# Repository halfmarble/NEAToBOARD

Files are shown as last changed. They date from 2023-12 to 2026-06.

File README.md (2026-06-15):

# NEAToBOARD

An open-source **ESP32-WROOM-32 development board** by [halfmarble](https://halfmarble.com), designed in KiCad. NEAToBOARD breaks the ESP32 out onto a breadboard-friendly board with USB, on-board programming, a battery power path, and a built-in set of I/O for learning and prototyping.

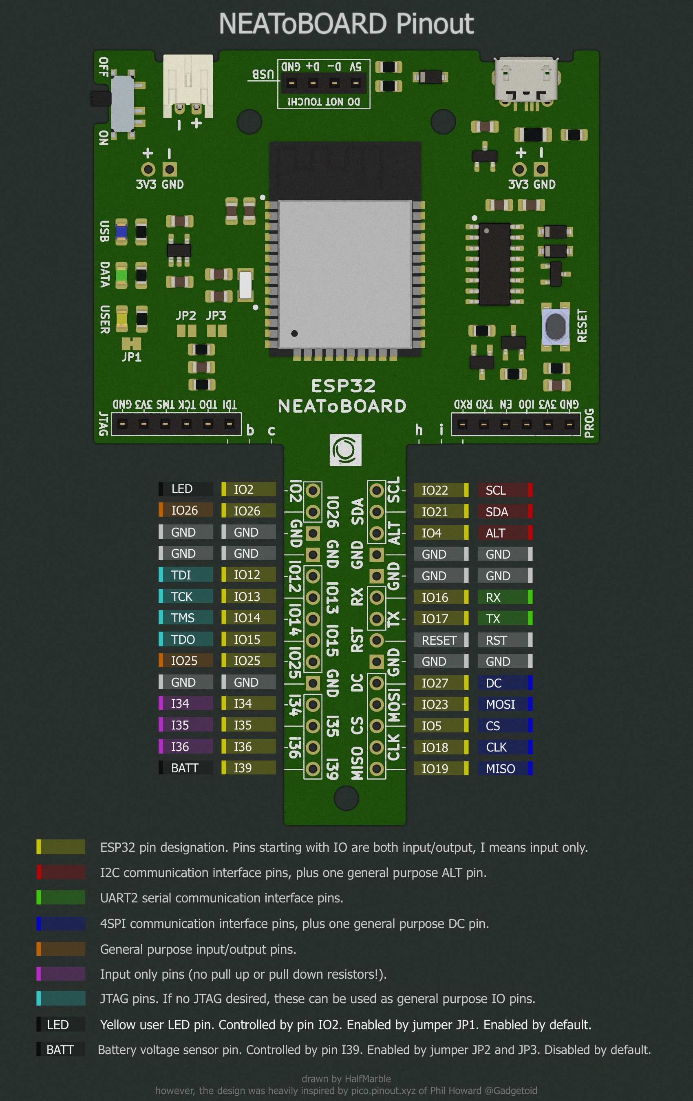
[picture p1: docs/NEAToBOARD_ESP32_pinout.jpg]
Pinout


## Features

- **ESP32-WROOM-32** module
- **USB micro-B** with a CH340C USB-to-UART bridge and the standard auto-reset / auto-bootloader circuit (no need to press buttons to flash)
- **Reset** and **two general-purpose** push buttons
- **Battery support** — JST-PH VBAT input with a Schottky power-path and a voltage divider for battery sensing, plus a 500 mA resettable fuse
- **32.768 kHz crystal** for the RTC / deep-sleep timekeeping
- On-board I/O for experimentation: a **5×4 LED matrix**, **RGB LED** (WS2812B), and discrete **feedback LEDs**
- **I²C** header plus a **Qwiic** connector, and an **SPI** header
- **JTAG** header for debugging
- M2 mounting holes; panelized with mouse-bite tabs

See the [full schematic (PDF)](docs/NEAToBOARD_ESP32.pdf) and the [pinout diagram](docs/NEAToBOARD_ESP32_pinout.jpg).

## Repository layout

```
hardware/
  KiCad-project/        KiCad 7 project — open NEAToBOARD_ESP32.kicad_pro
    NEAToBOARD_ESP32.kicad_sch        main schematic
    NEAToBOARD_ESP32Extras.kicad_sch  sub-sheet
    NEAToBOARD_ESP32.kicad_pcb        board layout
    HalfMarble.pretty/    project footprint library
    HalfMarble.3dshapes/  project 3D models (.step/.wrl) and symbols
    board2pdf.config.ini  board2pdf plugin config (fabrication PDFs)
    ibom.config.ini       InteractiveHtmlBom plugin config
    bom/                  rendered interactive BOM (bom.html)
    pinout/               pinout artwork source (pinout.pxd)
  3d/
    NEAToBOARD-ESP32.stl  3D-printable model of the board
docs/                   rendered schematic PDF and pinout image
BOM.csv                 bill of materials (values, footprints, manufacturer part numbers)
```

The authoritative source of truth is the KiCad schematic — `BOM.csv` is a convenience export so you can read the parts list without opening KiCad.

## Building / opening the design

Open `hardware/KiCad-project/NEAToBOARD_ESP32.kicad_pro` in **KiCad 7** (the files are saved in the `20221018` format). The custom footprint and 3D-model libraries are bundled inside the project and referenced with `${KIPRJMOD}`, so they load automatically — no global library setup required.

## Firmware

There is no firmware in this repository — NEAToBOARD runs **any ESP32 firmware**. Flash it with your toolchain of choice (Arduino core for ESP32, ESP-IDF, MicroPython, etc.) over the USB port; the on-board auto-reset/auto-bootloader circuit handles entering download mode, so no button presses are needed.

The pin layout is based on the **DFRobot FireBeetle ESP32** (with parts of **Adafruit's ESP32 board**). The simplest path is to target the **FireBeetle ESP32** board definition / pin map — most pins line up. If you select a different board definition, expect to **re-map a few GPIO assignments** to match this board; cross-check against the [pinout diagram](docs/NEAToBOARD_ESP32_pinout.jpg) and the [schematic](docs/NEAToBOARD_ESP32.pdf).

## Defensive publication / prior art

[`docs/defensive-publication/`](docs/defensive-publication/) contains a defensive
publication — *Synchronized Multi-Line Digital Signal Generation Using Plural Independent
Software-Triggered Serializer Peripherals With Open-Loop Fixed Start-Skew Compensation* —
published in the **Technical Disclosure Commons**, Defensive Publications Series
([www.tdcommons.org/dpubs_series/10442](https://www.tdcommons.org/dpubs_series/10442)), an
examiner-searched prior-art database, together with
load-bearing source excerpts. It documents, as dated public prior art, a technique for
synthesizing a USB full-speed D−/D+ differential signal on an ESP32 (a board like this
one) by driving two independent SPI controllers in lock-step: a CPU-fenced back-to-back
start makes the inter-unit skew deterministic, and a fixed configured MOSI delay cancels
it open-loop. It is published defensively to keep the technique freely practicable by all.

## License

The hardware design — schematic, PCB layout, footprint and 3D-model libraries, and the rest of the design files in this repository — is licensed under the **CERN Open Hardware Licence Version 2 – Permissive (CERN-OHL-P-2.0)**. See [`LICENSE`](LICENSE) for the full text. The defensive-publication document under [`docs/defensive-publication/`](docs/defensive-publication/) is licensed CC-BY-4.0, and the source excerpts therein retain their original Apache-2.0 headers.

> Copyright halfmarble 2023.
>
> This source describes Open Hardware and is licensed under the CERN-OHL-P v2. You may redistribute and modify this documentation and make products using it under the terms of the CERN-OHL-P v2 (https://ohwr.org/cern_ohl_p_v2.txt). This documentation is distributed WITHOUT ANY EXPRESS OR IMPLIED WARRANTY, INCLUDING OF MERCHANTABILITY, SATISFACTORY QUALITY AND FITNESS FOR A PARTICULAR PURPOSE. Please see the CERN-OHL-P v2 for applicable conditions.

## Acknowledgements

The pin layout and parts of the design are based on the [DFRobot FireBeetle ESP32](https://www.dfrobot.com/) and Adafruit's ESP32 board — both open-hardware designs. Thanks to those communities.

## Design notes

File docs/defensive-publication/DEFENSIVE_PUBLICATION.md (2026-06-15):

# Synchronized Multi-Line Digital Signal Generation Using Plural Independent Software-Triggered Serializer Peripherals With Open-Loop Fixed Start-Skew Compensation

**A Defensive Publication / Technical Disclosure to Establish Prior Art**

**Author:** Gerard Ziemski (Halfmarble LLC)
**Published:** Technical Disclosure Commons, Defensive Publications Series — [dpubs_series/10442](https://www.tdcommons.org/dpubs_series/10442)
**Date of first public disclosure:** 2026-06-05
**Version:** 1.0
**License:** Creative Commons Attribution 4.0 International (CC-BY-4.0).
*(The prior-art effect derives from the dated, enabling public disclosure itself, not from the license.)*
**Venue:** Technical Disclosure Commons, archived alongside the [halfmarble/NEAToBOARD](https://github.com/halfmarble/NEAToBOARD) open-hardware project.

---

> **Purpose of this document.** This is a *defensive publication*. It is released to
> place the techniques described herein, and reasonable generalizations of them, into
> the public domain as documented, dated, enabling prior art, so that they remain free
> for anyone to practice and cannot be removed from the public by a later patent. It is
> not an assertion of patent rights. The author makes no warranty and grants the
> permissions stated in the license above. A reference implementation predates this
> disclosure in the author's private records; this document is its first public
> disclosure.

---

## Abstract

A method is disclosed for generating two or more *time-aligned* digital output signals —
for example a differential pair such as the USB D−/D+ data lines, or more generally any
paired, differential, multi-phase, polyphase, quadrature, or multi-channel synchronized
output — on a microcontroller or system-on-chip (SoC) that provides **plural independent
hardware serializer peripherals** (such as two or more SPI master transmit/MOSI engines)
but provides **no single peripheral and no dedicated hardware** capable of driving the
desired multi-line signal directly. Each output line is assigned its own serializer and
preloaded with a precomputed bitstream. The serializers are started by **back-to-back
software trigger writes** (e.g., consecutive stores to each unit's start/command
register) that are preceded by CPU pipeline/memory-ordering **fence instructions**, which
quiesce the processor so that the unavoidable inter-unit start skew becomes **small,
fixed, and deterministic** rather than variable. That now-constant skew is then cancelled
**open-loop** by a single **fixed configured output delay** applied to the
later-emitting serializer (for example an SPI MOSI output delay expressed in fractions of
the bit clock, dummy lead bits, or a clock-phase offset), requiring no runtime
measurement or feedback. The result is that independent serializers, though triggered by
separate sequential software writes, emit in alignment to within a small fraction of a
bit period. A complete reduction to practice is described in which two SPI controllers of
an Espressif ESP32 synthesize a USB full-speed (12 Mbit/s) D−/D+ differential waveform,
enabling software USB host signaling on a chip lacking any USB peripheral.

## 1. Field and Motivation

Many digital interfaces carry information on two or more conductors that must transition
in a fixed, tight time relationship. The differential pair is the canonical case: a USB
receiver interprets the *difference* between D− and D+, so the two lines must be co-timed
to a small fraction of a bit period. Other examples include multi-phase clocking,
quadrature signaling, and multi-channel arbitrary waveform or LED-array generation where
channels must remain phase-aligned.

A microcontroller lacking dedicated hardware for such a signal (e.g., no USB
PHY/serial-interface engine, and no differential serializer) is conventionally forced to
"bit-bang" the signal by toggling general-purpose I/O (GPIO) from cycle-counted CPU code.
This consumes the CPU, is intolerant of interrupt jitter, and is limited by the per-bit
instruction budget — on common parts capping bit-banged USB at *low speed* (1.5 Mbit/s)
rather than *full speed* (12 Mbit/s).

A hardware serializer peripheral — for instance an SPI master operated transmit-only
(MOSI-only) — is effectively a hardware shift register that clocks a precomputed buffer
out of memory at a precise rate with no per-bit CPU involvement, and can therefore sustain
higher line rates. But a single such peripheral drives only **one** line, while the target
signal needs **two or more co-timed** lines. The natural idea — use one serializer per
line — runs into a synchronization problem: the serializers are independent units, each
started by its own trigger, and software can only trigger them in sequence, so one unit
begins shifting one or more instruction-times before the others. At high bit rates this
inter-unit *start skew* is a significant fraction of a bit period and corrupts the paired
signal. This disclosure solves that problem.

## 2. The Technique

The method comprises the following elements; elements (a)–(c) are the core combination,
and (d)–(g) are advantageous additions.

**(a) Per-line independent serializers.** Each of N ≥ 2 output lines is assigned to its
own independently-triggerable hardware serializer peripheral, each preloaded with the
precomputed bitstream for its line.

**(b) Deterministic-skew start via a CPU fence.** The serializers are triggered by writing
their respective start/trigger control values in **immediate succession** (e.g.,
consecutive stores to each unit's command register). Immediately *before* these writes, one
or more CPU pipeline/memory-ordering **fence/synchronization operations** are executed to
bring the processor to a quiescent state, so that the trigger writes issue with a
**minimal and deterministic** inter-unit skew (on the order of a single store
instruction) rather than a variable one influenced by prior in-flight memory or exception
activity.

**(c) Open-loop fixed compensating delay.** The later-emitting serializer(s) are
configured with a **fixed, constant output delay** sized to cancel the deterministic skew
from (b), so that all lines emit their first and subsequent bits in alignment. Because (b)
makes the skew constant, a single fixed delay value suffices; **no runtime feedback,
measurement, or closed-loop adjustment is required.**

**(d) Idle-level inversion with software pre-inversion.** Where the protocol idle level
differs from the serializer's idle level, one serializer's output path is inverted (e.g.,
via the I/O routing matrix or pin polarity) to rest at the protocol idle level, and that
line's data buffer is pre-inverted in software so the on-wire data remains correct.

**(e) Pre-encoded paired buffers.** The protocol physical layer (e.g., line coding such as
NRZI, run-length/bit-stuffing, framing, CRC) is computed ahead of time into per-line
buffers expressed as a sequence of per-bit line-state tuples, then split into the per-line
serializer buffers; buffers may reside in DMA-capable memory and may be allocated
contiguously for cache locality.

**(f) Clock targeting by search.** Serializer clock prescaler/divider settings are selected
by searching the divider space for the combination that most closely approximates a target
bit rate.

**(g) Execution-environment quiescing.** The trigger routine runs pinned to a processor
core at elevated priority and, during the timing-critical window, disables interrupts /
enters a critical section and resides in fast (non-cache-stalling) memory.

## 3. Reduction to Practice (Specific Embodiment: ESP32, USB Full Speed)

The following was reduced to practice on an Espressif ESP32 (dual-core Xtensa LX6), which
exposes two general-purpose SPI controllers ("HSPI" and "VSPI") and **no USB peripheral**.
Each controller is operated transmit-only (MOSI-only), 3-wire, half-duplex master. (Source
excerpts implementing the load-bearing steps accompany this document — see §7.)

- **Line/peripheral assignment.** USB **D− → GPIO12 via HSPI**; USB **D+ → GPIO13 via
  VSPI**. Together they form the USB differential pair.
- **Clock (element f).** A 12 MHz bit rate (USB full speed, ≈83.33 ns/bit) is obtained by
  iterating the controller prescaler and divider ranges and selecting the pair minimizing
  error versus 12 MHz; the resulting register value is programmed into both controllers.
  (`bitbangSPI.c`, `setup_clock`.)
- **Idle inversion (element d).** USB full speed idles with D+ high; an SPI line idles low.
  The D+ controller's serial output/input signal is routed through the I/O matrix with
  inversion enabled so the line idles high, and the D+ byte buffer is bitwise-complemented
  in software so the on-wire data is correct after the hardware inversion. Pin drive
  strength is set weak so an attached device can overpower the host lines as the protocol
  requires. (`bitbangSPI.c`, `bitbang_init`; `ubbPackets.c`, `_ubb_usb_add_description`.)
- **Encoding (element e).** For each packet (SOF, SETUP token, DATA/device-request,
  ACK/NAK), packet bytes are assembled with correct field order, bit-endianness, and
  CRC5/CRC16; the byte stream is NRZI-encoded with a forced transition stuffed after six
  consecutive 1s, and an EOP plus idle filler appended. Each symbol is expressed as a D−/D+
  level pair and written into the HSPI buffer (D−) and the pre-inverted VSPI buffer (D+),
  both in DMA-capable memory. (`ubbPackets.c`, `ubb_usb_add_data`; `crc.c`.)
- **Synchronized start (elements b, c).** With both controllers preloaded, the routine
  executes a fence — on Xtensa: `excw;` then `isync; dsync; esync;` then several `nop`s —
  immediately followed by back-to-back stores of the "user start" command value to each
  controller's command register (`spi1->cmd.val = ONE; spi2->cmd.val = ONE;`). The
  fence makes controller 1 lead controller 2 by a fixed, minimal interval. At
  initialization, a fixed MOSI output delay (expressed in eighths of the bit-clock period)
  is configured on the appropriate controller so that this constant skew is cancelled and
  D−/D+ transition together. An optional busy-spin waits for both units' start bits to
  self-clear. (`bitbangSPI.c`, `bitbang_write_impl` and the `delay` branch of
  `bitbang_init`.)
- **Timing isolation (element g).** The transmit routine runs as a highest-priority task
  pinned to the application core; during transmission it disables interrupts / enters a
  critical section (logging suppressed) and runs from instruction RAM. Inter-packet timing
  (e.g., 1 ms keep-alive SOF cadence) is produced by busy-wait.
- **Result.** The two independent controllers jointly emit a valid USB full-speed
  differential waveform sufficient to drive bus reset, keep-alive, and control transfers
  (e.g., a SET_ADDRESS enumeration step) on a microcontroller having no USB hardware.

## 4. Generalizations Disclosed (Defensive Scope)

The following generalizations are expressly disclosed as part of this prior art so that
neither the specific technique nor these variations may later be removed from the public
domain by patent:

- **Number of lines.** N ≥ 2 lines, each driven by its own serializer, triggered in
  succession, with a per-unit fixed compensating delay sized to each unit's deterministic
  skew.
- **Type of serializer.** Any hardware peripheral that shifts a buffer out at a clocked
  rate and is independently triggerable — SPI master MOSI, I2S/PCM transmitter, UART/USRT,
  dedicated shift-register block, timer output-compare/PWM-pattern engine, or programmable
  I/O serializer.
- **Means of making the skew deterministic.** Any pipeline/memory-barrier or
  instruction-ordering construct appropriate to the architecture (e.g., Xtensa
  `excw`/`isync`/`dsync`/`esync`, ARM `DSB`/`ISB`, RISC-V `fence`), and/or issuing the
  triggers from a single uninterruptible window, and/or any single-transaction multi-unit
  trigger the hardware permits.
- **Means of the compensating delay.** A configured serializer output delay, inserted
  fixed dummy/lead bits in the earlier-emitting buffer, a clock-phase offset, an earlier
  clock-enable of the lagging unit, or preamble padding — all **open-loop** (fixed,
  without runtime feedback).
- **Idle-level establishment.** Inverting one serializer's routed output with software
  pre-inversion, external inverting buffers, configurable pin polarity, or
  serializer idle/clock-polarity settings.
- **Target signal / protocol.** USB at low, full, or higher speeds as the processor
  allows; any other protocol or signal carried on two or more co-timed lines —
  differential, single-ended paired, multi-phase, polyphase, quadrature, or multi-channel
  phase-aligned (including multi-channel DAC or LED-array drive).
- **Processor/SoC.** Any single- or multi-core microcontroller or SoC with plural
  independent serializers. In a multi-core variant the per-line triggers may issue from
  different cores configured to fire within a bounded window, again with a fixed
  compensating delay.
- **Encoding.** Any line coding precomputed into the paired buffers as appropriate to the
  target protocol.

## 5. Relationship to Prior Art

This section surveys the surrounding public art and states precisely what is, and is not,
believed novel, so that the defensive disclosure is accurate and its distinguishing
combination is clear. Three categories of prior art are adjacent but distinct.

**5.1 Single peripheral driving multiple lines (no inter-unit skew exists).**
A large body of work drives several output lines from **one** serializer or one
parallel-output peripheral, so the synchronization problem addressed here does not arise:
ESP32/ESP8266 LED drivers serialize many parallel LED lanes from a **single I2S**
peripheral with DMA — e.g., the FastLED ESP32 parallel driver [7], the
*I2SClocklessLedDriver* (16 lanes from one I2S) [6], and cnlohr's *esp8266ws2812i2s*
(WS2812 from one I2S) [11]; quad-SPI (QSPI) drives four synchronized data lines from a
**single** master, e.g., US 9,734,099 B1 [10]. Inter-line alignment in all these is
inherent to using one peripheral and is **not** the problem solved here.

**5.2 Repurposing one serializer as a bit-stream generator for an unsupported protocol.**
Vendor application notes emulate one protocol with a single peripheral of another type —
e.g., I²S emulated on a **single SPI** with a timer generating the word-select frame: ST
AN5086 [4] and NXP AN4944 [12]. These establish the general idea of abusing a serializer
as a bitstream generator, but use a **single** unit and therefore present **no inter-unit
start-skew** to solve.

**5.3 Multi-serializer alignment by hardware clock sync or closed-loop skew control.**
Where multiple serializers *are* aligned, the art does so by **hardware** means, not by a
software-fenced start plus open-loop fixed delay on a commodity MCU:

- **FPGA SERDES:** multiple OSERDES blocks are aligned by a **shared, phase-aligned clock
  and a common synchronous reset**, optionally with a forwarded-clock training pattern —
  Xilinx XAPP585 [8] and XAPP704 (16 OSERDES from one clocking module) [9].
- **Cross-chip clock injection:** synchronizing serializers across separate RP2040 chips
  is done by driving a common oscillator into each chip's clock input and using PIO
  synchronized interrupts — Weber et al. (2025) [13].
- **Integrated / closed-loop skew compensation:** per-channel programmable skew delays
  exist **inside integrated multi-channel transmitters/SERDES**, set from on-chip
  registers/SRAM (US 8,081,706 B2 [1]), as fine analog differential pre-skew (US
  2015/0028929 A1 [2]), or **tuned by receiver feedback** to meet an interface spec such
  as SFI-5 (US 7,467,056 [3]); related receive-side deskew appears in TI TIDUA38 [14].
  These are integrated and/or closed-loop, not an open-loop fixed delay applied to a
  second discrete, software-started serializer.

**5.4 What is believed novel — the combination.** No located prior art combines all of:
(i) **two or more fully independent serializer peripherals** on one MCU/SoC, each driving
one line of a co-timed multi-line output; (ii) started by **back-to-back software trigger
writes made deterministic by a CPU pipeline/memory fence**; (iii) with inter-unit start
skew cancelled **open-loop by a single fixed configured output delay** (no feedback); and
(iv) applied to produce a **differential (or otherwise paired/multi-phase) signal on a
part that has no native peripheral for that signal** — reduced to practice as a USB
full-speed D−/D+ generator on the ESP32. The contribution is this *combination*; each
ingredient individually is known, but their assembly to solve co-timed multi-line output
on a commodity MCU without dedicated hardware is not shown in the located art. (This is an
absence-of-evidence conclusion over a non-exhaustive public corpus, not a proof of
non-existence.)

## 6. Statement for the Public Record

The author publishes the technique of §2, the embodiment of §3, and the generalizations of
§4 as prior art, effective on the date of first public disclosure stated above, to ensure
they remain freely practicable by all and to bar their later removal from the public
domain by patent.

## 7. Reference Implementation (Excerpts)

The load-bearing portions of a working reference implementation (from the author's
"ubbUSB" Espressif ESP-IDF / PlatformIO project) accompany this disclosure in
[`reference-excerpts/`](reference-excerpts/), under the Apache License 2.0:

- **`bitbangSPI.c` / `bitbangSPI.h`** — dual independent SPI-controller initialization
  (`bitbang_init`), the fixed compensating MOSI delay (the `delay` branch), the
  brute-force clock search (`setup_clock`), and the fenced back-to-back synchronized start
  (`bitbang_write_impl`).
- **`ubbPackets.c` / `ubbPackets.h`** — the encoder: NRZI, bit-stuffing, EOP/framing, and
  the splitting of per-bit D−/D+ line-state pairs into the two per-line serializer buffers
  (`ubb_usb_add_data`, `_ubb_usb_add_description`), plus packet construction.
- **`crc.c` / `crc.h`** — USB CRC5 (token) and CRC16 (data) per the USB specification.

These are excerpts intended to make the disclosure enabling on the core claims; they are
not a standalone-buildable project (the full ubbUSB project additionally contains the
transmit task, top-level state machine, and build files). The excerpt files retain their
original Apache-2.0 headers; this disclosure document is CC-BY-4.0; the surrounding
NEAToBOARD hardware project is licensed separately (CERN-OHL-2). 

## References

[1] US 8,081,706 B2, *Reducing lane-to-lane skew* (per-channel SRAM-set delay in a
multi-channel transmitter). https://patents.google.com/patent/US8081706

[2] US 2015/0028929 A1, *Differential pre-skew* (fine analog delay ~0–28 ps).
https://patents.google.com/patent/US20150028929A1/en

[3] US 7,467,056, *Per-lane preskew tuned by receiver feedback (SFI-5)*.
https://image-ppubs.uspto.gov/dirsearch-public/print/downloadPdf/7467056

[4] STMicroelectronics, AN5086, *I2S protocol emulation on STM32L0 using a standard SPI
peripheral*.
https://www.st.com/resource/en/application_note/an5086-i2s-protocol-emulation-on-stm32l0-series-microcontrollers-using-a-standard-spi-peripheral-stmicroelectronics.p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

[5] ESP-IDF SPI Master driver documentation (ESP32 GP-SPI controllers SPI2/SPI3;
per-controller start). https://docs.espressif.com/projects/esp-idf/en/stable/esp32/api-reference/peripherals/spi_master.html

[6] hpwit, *I2SClocklessLedDriver* — 16 parallel LED lanes from one ESP32 I2S.
https://github.com/hpwit/I2SClocklessLedDriver

[7] FastLED, ESP32 parallel-output driver (single I2S, multiple lanes).
https://github.com/FastLED/FastLED/blob/master/src/platforms/esp/32/README.md

[8] Xilinx, XAPP585, *OSERDES output alignment via synchronous reset and forwarded clock*.
https://docs.amd.com/api/khub/documents/JlDZcsu8DsMLJ6KXAZfq5Q/content

[9] Xilinx, XAPP704, *16 OSERDES driven from one TX_CLOCKS clocking module*.
http://www.altera.co.kr/_xilinx/html/ref/V4AdvantageCD2/content/source/xapp704.pdf

[10] US 9,734,099 B1/B2, *Synchronized multi-line (QSPI) output from a single master*.
https://patents.google.com/patent/US9734099B1/en

[11] cnlohr, *esp8266ws2812i2s* — WS2812 LEDs via one ESP8266 I2S + DMA.
https://github.com/cnlohr/esp8266ws2812i2s

[12] NXP, AN4944, *Emulating I2S bus on Kinetis-M using SPI plus a timer for word-select*.
https://www.nxp.com/docs/en/application-note/AN4944.pdf

[13] Weber et al., *Synchronizing RP2040 serializers via common oscillator into XIN and
PIO synchronized interrupts*, IET (2025).
https://ietresearch.onlinelibrary.wiley.com/doi/full/10.1049/tje2.70067

[14] Texas Instruments, TIDUA38, *Receive-side (MISO) signal-path delay compensation*.
https://www.ti.com/lit/pdf/tidua38

[15] US 2007/0047667 A1; US 8,132,040 — additional inter-channel skew-compensation art.
https://patents.google.com/patent/US20070047667A1/en ·
https://www.freepatentsonline.com/8132040.html

---

*Prepared as a defensive publication. Not legal advice. Depositing this document publicly
(Technical Disclosure Commons [dpubs_series/10442](https://www.tdcommons.org/dpubs_series/10442); GitHub) is
a public disclosure establishing prior art as of the date above.*

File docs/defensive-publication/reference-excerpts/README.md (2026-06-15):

# Reference-implementation excerpts

These files are **excerpts** from the author's private *ubbUSB* project (an Espressif
ESP-IDF / PlatformIO firmware experiment), included to make the accompanying defensive
publication — [`../DEFENSIVE_PUBLICATION.md`](../DEFENSIVE_PUBLICATION.md),
Technical Disclosure Commons [dpubs_series/10442](https://www.tdcommons.org/dpubs_series/10442) — *enabling* on its
core claims.

They are provided **as-is, under the Apache License 2.0** (see the header in each file),
and are **not a standalone-buildable project**: the full ubbUSB project additionally
contains the transmit task, the top-level USB state machine, utility headers, and the
PlatformIO/ESP-IDF build files, which are not reproduced here.

| File | Role in the disclosed technique |
|---|---|
| `bitbangSPI.c` / `bitbangSPI.h` | Dual independent SPI-controller init (`bitbang_init`); fixed compensating MOSI delay (`delay` branch); brute-force clock search (`setup_clock`); **fenced back-to-back synchronized start** (`bitbang_write_impl`). |
| `ubbPackets.c` / `ubbPackets.h` | NRZI + bit-stuffing + EOP/framing encoder; splitting per-bit D−/D+ line-state pairs into the two per-line serializer buffers (`ubb_usb_add_data`, `_ubb_usb_add_description`). |
| `crc.c` / `crc.h` | USB CRC5 (token) and CRC16 (data) per the USB specification. |

The synchronized-start core is in `bitbangSPI.c`, function `bitbang_write_impl`: a
`excw; isync; dsync; esync;` fence and NOP padding immediately precede the two back-to-back
writes of the SPI "user start" bit to each controller's command register, after which the
fixed MOSI delay configured in `bitbang_init` cancels the resulting one-instruction skew.

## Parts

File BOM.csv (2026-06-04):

Reference | Value | Footprint | Qty | Manufacturer | Manufacturer Part Number
C1, C6 | 10uF | HalfMarble:C_0805_2012Metric_Pad1.18x1.45mm_HandSolder | 2 | Samsung Electro-Mechanics | CL21A106KPFNNNE
C2-C5, C7, C8, C11, C12 | 1uF | HalfMarble:C_0805_2012Metric_Pad1.18x1.45mm_HandSolder | 8 | Samsung Electro-Mechanics | CL21B105KOFNNNE
C9, C10 | 12pF | HalfMarble:C_0805_2012Metric_Pad1.18x1.45mm_HandSolder | 2 | YAGEO | CC0805JRNPO9BN120
D1, D3, D28 | BAT20J | HalfMarble:D_SOD-123 | 3 | Changjiang Electronics Tech (CJ) | B5819W
D2, D8-D27 | GREEN | HalfMarble:LED_0805_2012Metric_Pad1.15x1.40mm_HandSolder | 21 | XINGLIGHT | XL-2012UGC
D4 | BLUE | HalfMarble:LED_0805_2012Metric_Pad1.15x1.40mm_HandSolder | 1 | XINGLIGHT | XL-2012UBC
D5, D7 | YELLOW | HalfMarble:LED_0805_2012Metric_Pad1.15x1.40mm_HandSolder | 2 | Everlight Elec | 17-21SYGC/S530-E2/TR8
D6 | WS2812B | HalfMarble:LED_WS2812B_PLCC4_5.0x5.0mm_P3.2mm | 1 | Worldsemi | WS2812B-B/W
D29 | RED | HalfMarble:LED_0805_2012Metric_Pad1.15x1.40mm_HandSolder | 1 | Everlight Elec | 17-21SURC/S530-A3/TR8
F1 | 500mA | HalfMarble:Fuse_1206_3216Metric | 1 | Jinrui Electronic Materials Co. | JK-NSMD050-13.2V
H1-H3 | MountingHole | HalfMarble:MountingHole_2.2mm_M2_ISO7380 | 3
J1 | USB_B_Micro | HalfMarble:USB_Micro-B_Molex-105017-0001 | 1 | SHOU HAN | MicroXNJ
J2, J3 | 3.3V | HalfMarble:PinHeader_1x02_P2.54mm_Vertical | 2 | Nextron(Nextronics Engineering)
J4 | VBAT IN | HalfMarble:JST_PH_S2B-PH-K_1x02_P2.00mm_Horizontal | 1 | Ckmtw(Shenzhen Cankemeng)
J5 | JTAG | HalfMarble:PinSocket_1x06_P2.54mm_Vertical | 1 | BOOMELE(Boom Precision Elec)
J6, J7 | Header_01x14 | HalfMarble:PinHeader_1x14_P2.54mm_Vertical | 2 | Nextron(Nextronics Engineering) | Z-211-4011-0021-001
J8 | PROGRAM | HalfMarble:PinSocket_1x06_P2.54mm_Vertical | 1 | BOOMELE(Boom Precision Elec)
J9, J10, J15 | Header_01x01 | HalfMarble:PinHeader_1x01_P2.54mm_Small | 3
J11, J28 | Header_01x05 | HalfMarble:PinHeader_1x05_P2.54mm_Vertical | 2 | Nextron(Nextronics Engineering)
J12-J14, J16-J18, J26, J27, J29, J30 | Header_01x02 | HalfMarble:PinHeader_1x02_P2.54mm_Vertical | 10 | Nextron(Nextronics Engineering)
J19, J20, J24 | Socket_01x05 | HalfMarble:PinSocket_1x05_P2.54mm_Vertical | 3 | BOOMELE(Boom Precision Elec)
J21 | Socket_01x04 | HalfMarble:PinSocket_1x04_P2.54mm_Vertical | 1 | BOOMELE(Boom Precision Elec)
J22, J23 | Qwiic | HalfMarble:CONN_BM04B-SRSS-TB(LF)(SN) | 2 | JST Sales America | BM04B-SRSS-TB(LF)(SN)
J25 | Socket_01x02 | HalfMarble:PinSocket_1x02_P2.54mm_Vertical | 1 | BOOMELE(Boom Precision Elec)
J31 | Header_01x03 | HalfMarble:PinHeader_1x03_P2.54mm_Vertical | 1 | Nextron(Nextronics Engineering)
JP1, JP2 | Jumper (open) | HalfMarble:SolderJumper-2_P1.3mm_Open_Pad1.0x1.5mm | 2
JP3, JP4 | Jumper (bridged) | HalfMarble:SolderJumper-2_P1.3mm_Bridged_Pad1.0x1.5mm_Small | 2
LOGO1-LOGO3 | Logo_HalfMarble (silkscreen) | HalfMarble:LOGO | 3
LOGO4 | Logo_Open_Hardware (silkscreen) | Symbol:OSHW-Logo2_7.3x6mm_SilkScreen | 1
Q1, Q3 | S8050 | HalfMarble:TSOT-23 | 2 | Changjiang Electronics Tech (CJ) | S8050
Q2 | Si2301 | HalfMarble:SOT-23 | 1 | Vishay Intertech | SI2301CDS-T1-GE3
R1, R4, R5, R10, R17 | 10K | HalfMarble:R_0805_2012Metric_Pad1.20x1.40mm_HandSolder | 5 | Uniroyal Elec | 0805W8F1002T5E
R2 | 100K | HalfMarble:R_0805_2012Metric_Pad1.20x1.40mm_HandSolder | 1 | Uniroyal Elec | 0805W8J0104T5E
R3, R8, R11-R16, R20 | 2.7K | HalfMarble:R_0805_2012Metric_Pad1.20x1.40mm_HandSolder | 9 | Uniroyal Elec | 0805W8F2701T5E
R6, R9 | 470K 0.1% | HalfMarble:R_0805_2012Metric_Pad1.20x1.40mm_HandSolder | 2 | YAGEO | RT0805BRE07470RL
R7 | 3.9K | HalfMarble:R_0805_2012Metric_Pad1.20x1.40mm_HandSolder | 1 | Uniroyal Elec | 0805W8F3901T5E
R18, R19 | 22 | HalfMarble:R_0805_2012Metric_Pad1.20x1.40mm_HandSolder | 2 | Uniroyal Elec | 0805W8J0220T5E
R21, R22 | EMPTY (do not populate) | HalfMarble:R_0805_2012Metric_Pad1.20x1.40mm_HandSolder | 2
SW1, SW3-SW5 | Switch small | HalfMarble:PTS810SJG250SMTRLFS | 4 | Korean Hroparts Elec | K2-1808SN-A4SW-01
SW2 | Toggle | HalfMarble:SWITCH_SPST_SMD_A | 1 | Korean Hroparts Elec | K3-1296S-E1
U1 | USB LDO XC6206 | HalfMarble:SOT-23 | 1 | Torex Semicon | XC6206P332MR
U2 | USB-Serial CH340C | HalfMarble:SOIC-16_3.9x9.9mm_P1.27mm | 1 | WCH(Jiangsu Qin Heng) | CH340C
U3 | Main LDO ME6211 | HalfMarble:SOT-23-5 | 1 | MICRONE(Nanjing Micro One Elec) | ME6211C33M5G-N
U4 | ESP32-WROOM-32D | HalfMarble:ESP32-WROOM-32 | 1 | Espressif Systems | ESP32-WROOM-32D
U5, U8, U13, U16 | MouseBite (panel tab) | HalfMarble:MouseBiteHalf | 4
U6, U7, U9-U12, U14, U15 | MouseBite (panel tab) | HalfMarble:MouseBite | 8
Y1 | 32.768kHz crystal | HalfMarble:XTAL_ABS07-32.768KHZ-T | 1 | Seiko Epson | Q13FC1350000400

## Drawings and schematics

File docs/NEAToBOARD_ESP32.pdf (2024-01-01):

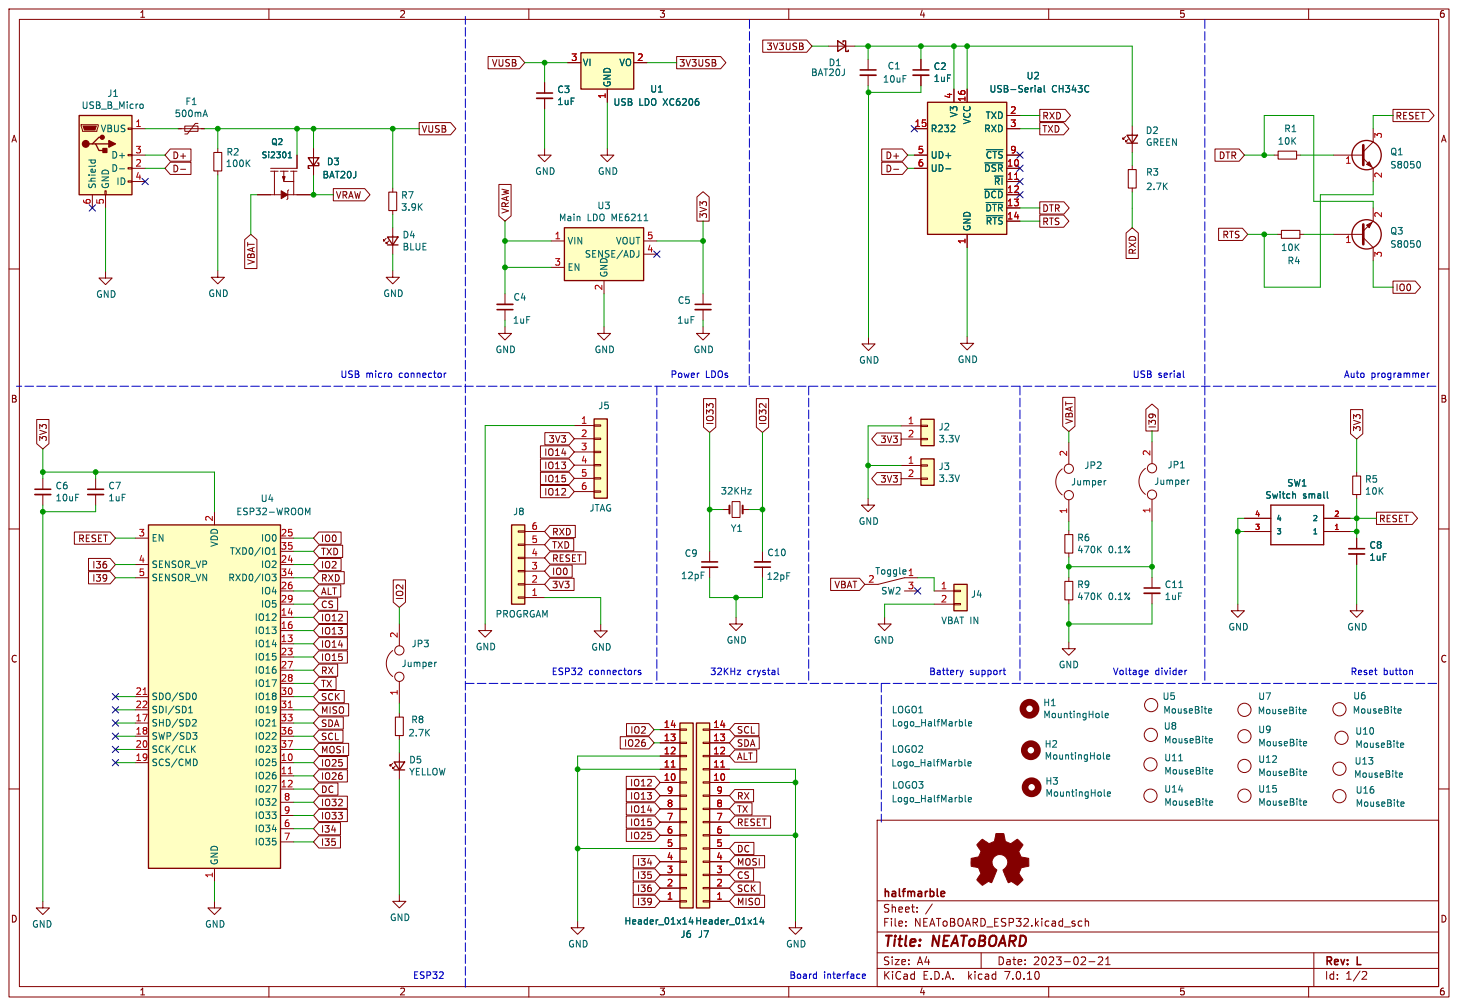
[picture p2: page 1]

1 VO 2 VI 3 U1 USB LDO XC6206 VIN 1 GND
GNDGND
1uF GND

4 UD+ 5 UD- 6 ~{CTS}9 U2 USB-Serial CH343C

1 ~{DSR} 10 ~{RI} 11 ~{DCD} 12 ~{DTR} 13 ~{RTS} 14 R232 15 VCC 16 TXD 2 RXD 3 V3

2 EN 3 SENSE/ADJ 4 VOUT 5 U3 Main LDO ME6211

2 SCK/CLK 20 SDO/SD0 21 SDI/SD1 22

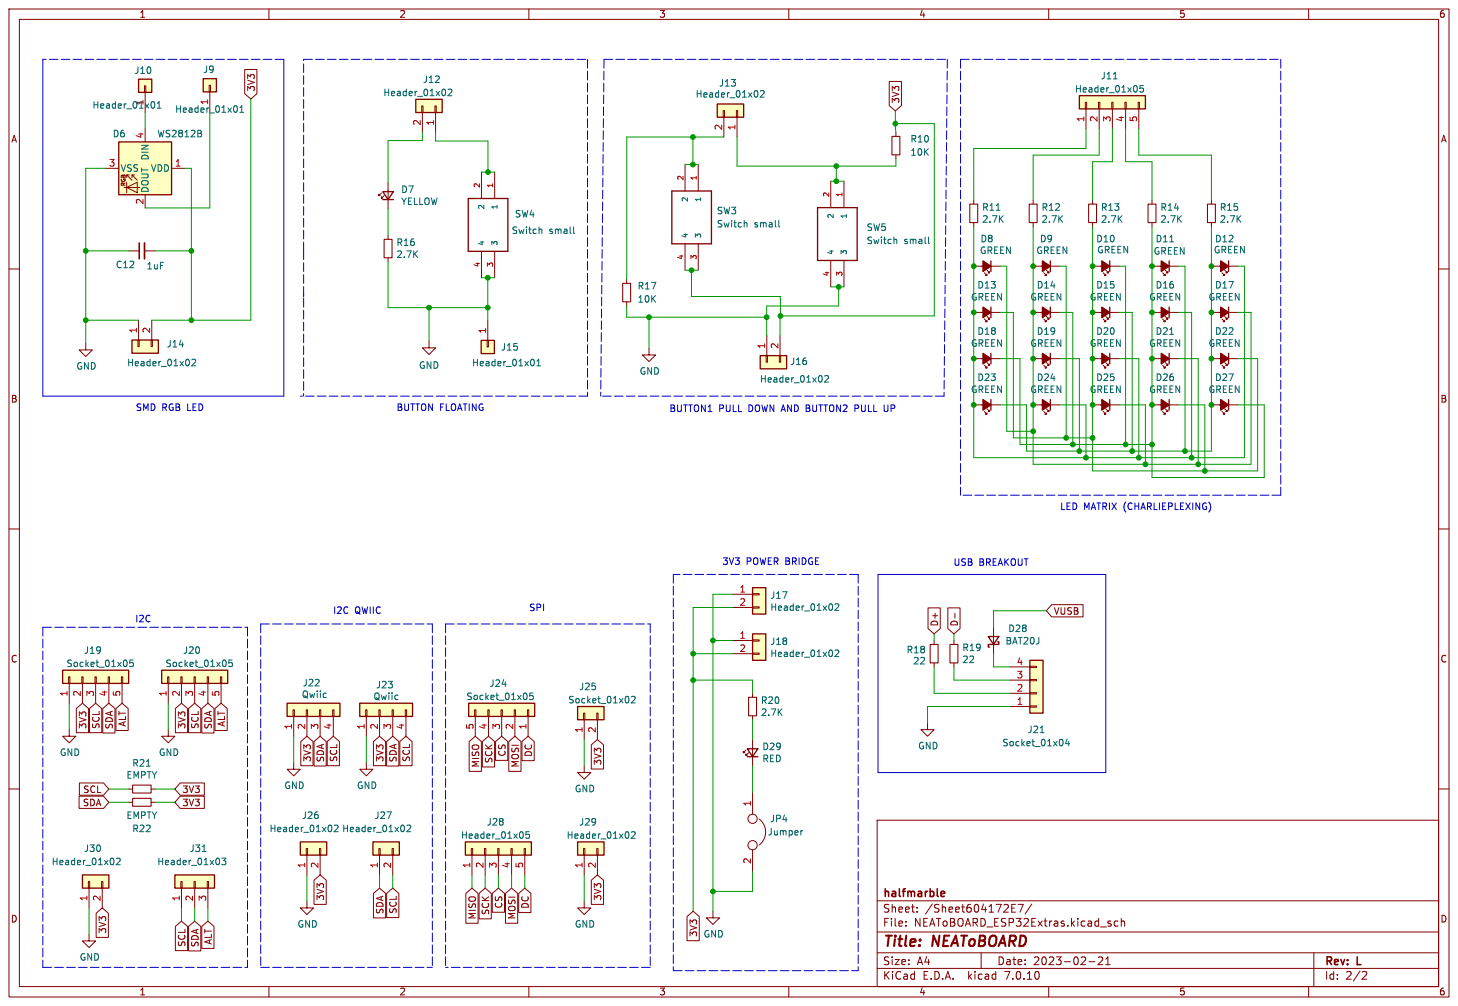
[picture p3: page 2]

USB BREAKOUT BUTTON1 PULL DOWN AND BUTTON2 PULL UP

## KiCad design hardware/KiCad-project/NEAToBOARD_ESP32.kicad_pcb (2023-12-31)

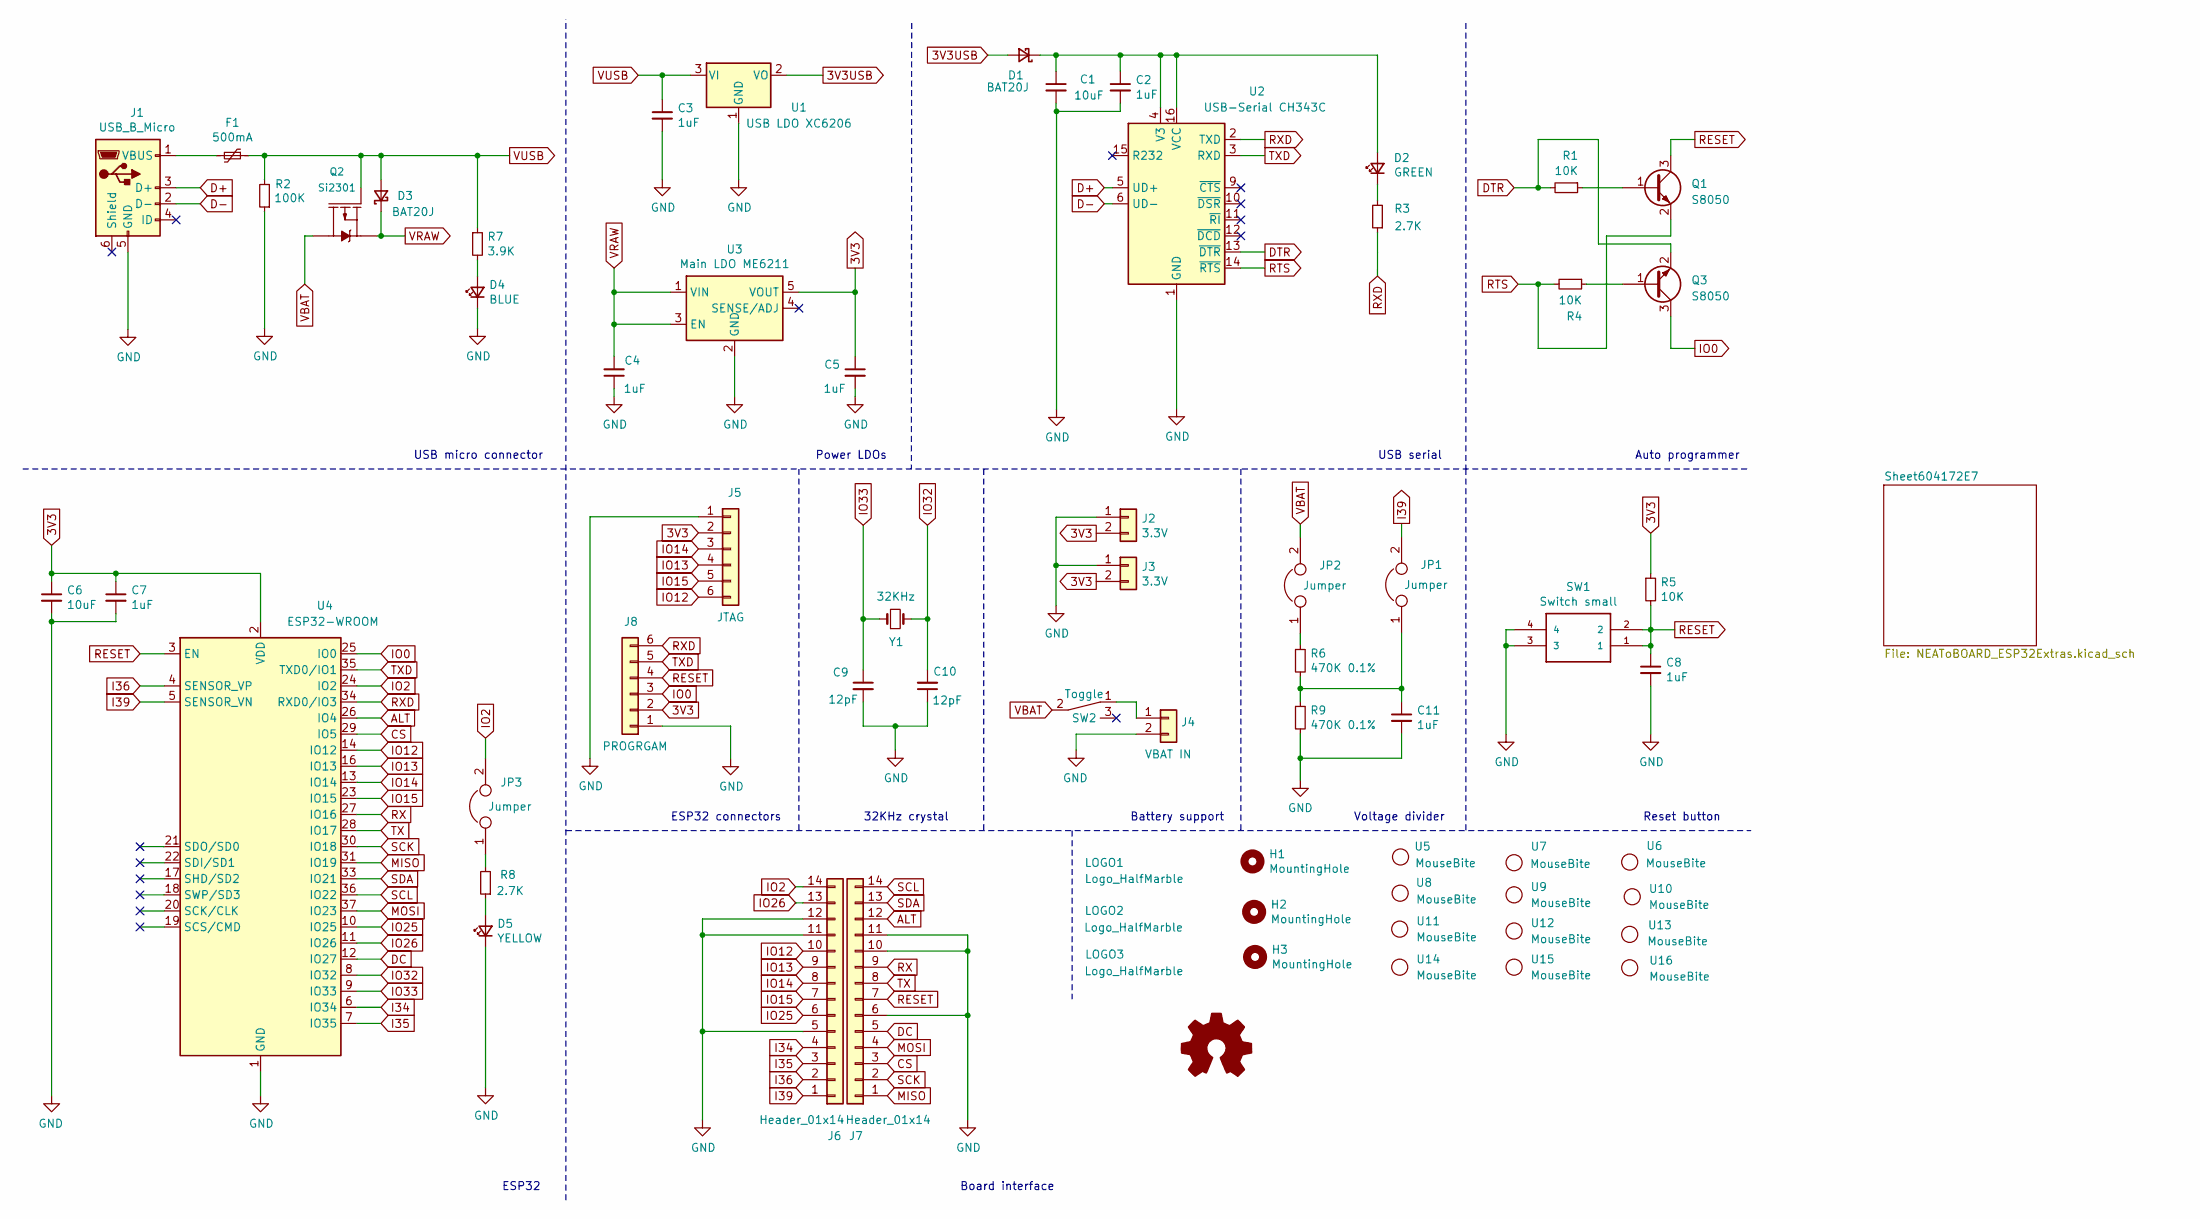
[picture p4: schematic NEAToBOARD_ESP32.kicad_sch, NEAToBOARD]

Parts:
C1, C6: 10uF; C_0805_2012Metric_Pad1.18x1.45mm_HandSolder; MANUFACTURER_PART_NUMBER CL21A106KPFNNNE; LCSC C17024
C2, C3, C4, C5, C7, C8, C11: 1uF; C_0805_2012Metric_Pad1.18x1.45mm_HandSolder; MANUFACTURER_PART_NUMBER CL21B105KOFNNNE; LCSC C24123
C9, C10: 12pF; C_0805_2012Metric_Pad1.18x1.45mm_HandSolder; MANUFACTURER_PART_NUMBER CC0805JRNPO9BN120; LCSC C107108
D1, D3: BAT20J; D_SOD-123; MANUFACTURER_PART_NUMBER B5819W; LCSC C8598
D2: GREEN; LED_0805_2012Metric_Pad1.15x1.40mm_HandSolder; MANUFACTURER_PART_NUMBER XL-2012UGC; LCSC C965815
D4: BLUE; LED_0805_2012Metric_Pad1.15x1.40mm_HandSolder; MANUFACTURER_PART_NUMBER XL-2012UBC; LCSC C965817
D5: YELLOW; LED_0805_2012Metric_Pad1.15x1.40mm_HandSolder; MANUFACTURER_PART_NUMBER 17-21SYGC/S530-E2/TR8; LCSC C73548
F1: 500mA; Fuse_1206_3216Metric; MANUFACTURER_PART_NUMBER JK-NSMD050-13.2V; LCSC C369159
H1, H2, H3: MountingHole; MountingHole_2.2mm_M2_ISO7380
J1: USB_B_Micro; USB_Micro-B_Molex-105017-0001; MANUFACTURER_PART_NUMBER MicroXNJ; LCSC C404969
J2, J3: 3.3V; PinHeader_1x02_P2.54mm_Vertical; LCSC C113597
J4: VBAT IN; JST_PH_S2B-PH-K_1x02_P2.00mm_Horizontal; MANUFACTURER_PART_NUMBER C155876; LCSC C155876
J5: JTAG; PinSocket_1x06_P2.54mm_Vertical; LCSC C40877
J6, J7: Header_01x14; PinHeader_1x14_P2.54mm_Vertical; MANUFACTURER_PART_NUMBER Z-211-4011-0021-001; LCSC C113597
J8: PROGRGAM; PinSocket_1x06_P2.54mm_Vertical; LCSC C40877
JP1, JP2: Jumper; SolderJumper-2_P1.3mm_Open_Pad1.0x1.5mm
JP3: Jumper; SolderJumper-2_P1.3mm_Bridged_Pad1.0x1.5mm_Small
LOGO1, LOGO2, LOGO3: Logo_HalfMarble; LOGO
LOGO4: Logo_Open_Hardware_Small; OSHW-Logo2_7.3x6mm_SilkScreen
Q1, Q3: S8050; TSOT-23; MANUFACTURER_PART_NUMBER S8050; LCSC C2146
Q2: Si2301; SOT-23; MANUFACTURER_PART_NUMBER SI2301CDS-T1-GE3; LCSC C10487
R1, R4, R5: 10K; R_0805_2012Metric_Pad1.20x1.40mm_HandSolder; MANUFACTURER_PART_NUMBER 0805W8F1002T5E; LCSC C17414
R2: 100K; R_0805_2012Metric_Pad1.20x1.40mm_HandSolder; MANUFACTURER_PART_NUMBER 0805W8J0104T5E; LCSC C25611
R3, R8: 2.7K; R_0805_2012Metric_Pad1.20x1.40mm_HandSolder; MANUFACTURER_PART_NUMBER 0805W8F2701T5E; LCSC C17530
R6, R9: 470K 0.1%; R_0805_2012Metric_Pad1.20x1.40mm_HandSolder; MANUFACTURER_PART_NUMBER RT0805BRE07470RL; LCSC C706281
R7: 3.9K; R_0805_2012Metric_Pad1.20x1.40mm_HandSolder; MANUFACTURER_PART_NUMBER 0805W8F3901T5E; LCSC C17614
SW1: Switch small; PTS810SJG250SMTRLFS; MANUFACTURER_PART_NUMBER K2-1808SN-A4SW-01; LCSC C92589
SW2: Toggle; SWITCH_SPST_SMD_A; MANUFACTURER_PART_NUMBER K3-1296S-E1; LCSC C128955
U1: USB LDO XC6206; SOT-23; MANUFACTURER_PART_NUMBER XC6206P332MR; LCSC C5446
U2: USB-Serial CH343C; SOIC-16_3.9x9.9mm_P1.27mm; MANUFACTURER_PART_NUMBER CH340C; LCSC C7464026
U3: Main LDO ME6211; SOT-23-5; MANUFACTURER_PART_NUMBER ME6211C33M5G-N; LCSC C82942
U4: ESP32-WROOM; ESP32-WROOM-32; MANUFACTURER_PART_NUMBER ESP32-WROOM-32E-N16; LCSC C701343
U5, U8, U13, U16: MouseBite; MouseBiteHalf
U6, U7, U9, U10, U11, U12, U14, U15: MouseBite
Y1: 32KHz; XTAL_ABS07-32.768KHZ-T; MANUFACTURER_PART_NUMBER Q13FC1350000400; LCSC C32346

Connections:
3V3USB: D1.2 (A), U1.2 (VO)
ALT: J7.12, U4.26 (IO4); also elsewhere on the board
CS: J7.3, U4.29 (IO5); also elsewhere on the board
D+: J1.3 (D+), U2.5 (UD+); also elsewhere on the board
D-: J1.2 (D-), U2.6 (UD-); also elsewhere on the board
DC: J7.5, U4.12 (IO27); also elsewhere on the board
DTR: Q3.2 (E), R1.2, U2.13 (~DTR)
I34: J6.4, U4.6 (IO34)
I35: J6.3, U4.7 (IO35)
I36: J6.2, U4.4 (SENSOR_VP)
I39: J6.1, JP1.2, U4.5 (SENSOR_VN)
IO0: J8.3, Q3.3 (C), U4.25 (IO0)
IO2: J6.14, JP3.2, U4.24 (IO2)
IO12: J5.6, J6.10, U4.14 (IO12)
IO13: J5.4, J6.9, U4.16 (IO13)
IO14: J5.3, J6.8, U4.13 (IO14)
IO15: J5.5, J6.7, U4.23 (IO15)
IO25: J6.6, U4.10 (IO25)
IO26: J6.13, U4.11 (IO26)
IO32: C10.2, U4.8 (IO32), Y1.2
IO33: C9.1, U4.9 (IO33), Y1.1
MISO: J7.1, U4.31 (IO19); also elsewhere on the board
MOSI: J7.4, U4.37 (IO23); also elsewhere on the board
unnamed: C11.1, JP1.1, R6.2, R9.1
unnamed: C1.1, C2.1, D1.1 (K), D2.2 (A), U2.4 (V3), U2.16 (VCC)
unnamed: D2.1 (K), R3.2
unnamed: D4.2 (A), R7.2
unnamed: D5.2 (A), R8.1
unnamed: F1.2, J1.1 (VBUS)
unnamed: J4.1, SW2.1
unnamed: JP2.1, R6.1
unnamed: JP3.1, R8.2
unnamed: Q1.1 (B), R1.1
unnamed: Q3.1 (B), R4.1
RESET: C8.1, J7.7, J8.4, Q1.3 (C), R5.2, SW1.1, SW1.2, U4.3 (EN)
RTS: Q1.2 (E), R4.2, U2.14 (~RTS)
RX: J7.9, U4.27 (IO16)
RXD: J8.6, R3.1, U2.2 (TXD), U4.34 (RXD0/IO3)
SCK: J7.2, U4.30 (IO18); also elsewhere on the board
TX: J7.8, U4.28 (IO17)
TXD: J8.5, U2.3 (RXD), U4.35 (TXD0/IO1)
VBAT: JP2.2, Q2.3 (D), SW2.2
VRAW: C4.2, D3.1 (K), Q2.2 (S), U3.1 (VIN), U3.3 (EN)
VUSB: C3.1, D3.2 (A), F1.1, Q2.1 (G), R2.2, R7.1, U1.3 (VI); also elsewhere on the board

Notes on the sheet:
Voltage divider
Board interface
Battery support
Reset button
32KHz crystal
ESP32
Auto programmer
Power LDOs
USB serial
ESP32 connectors
USB micro connector

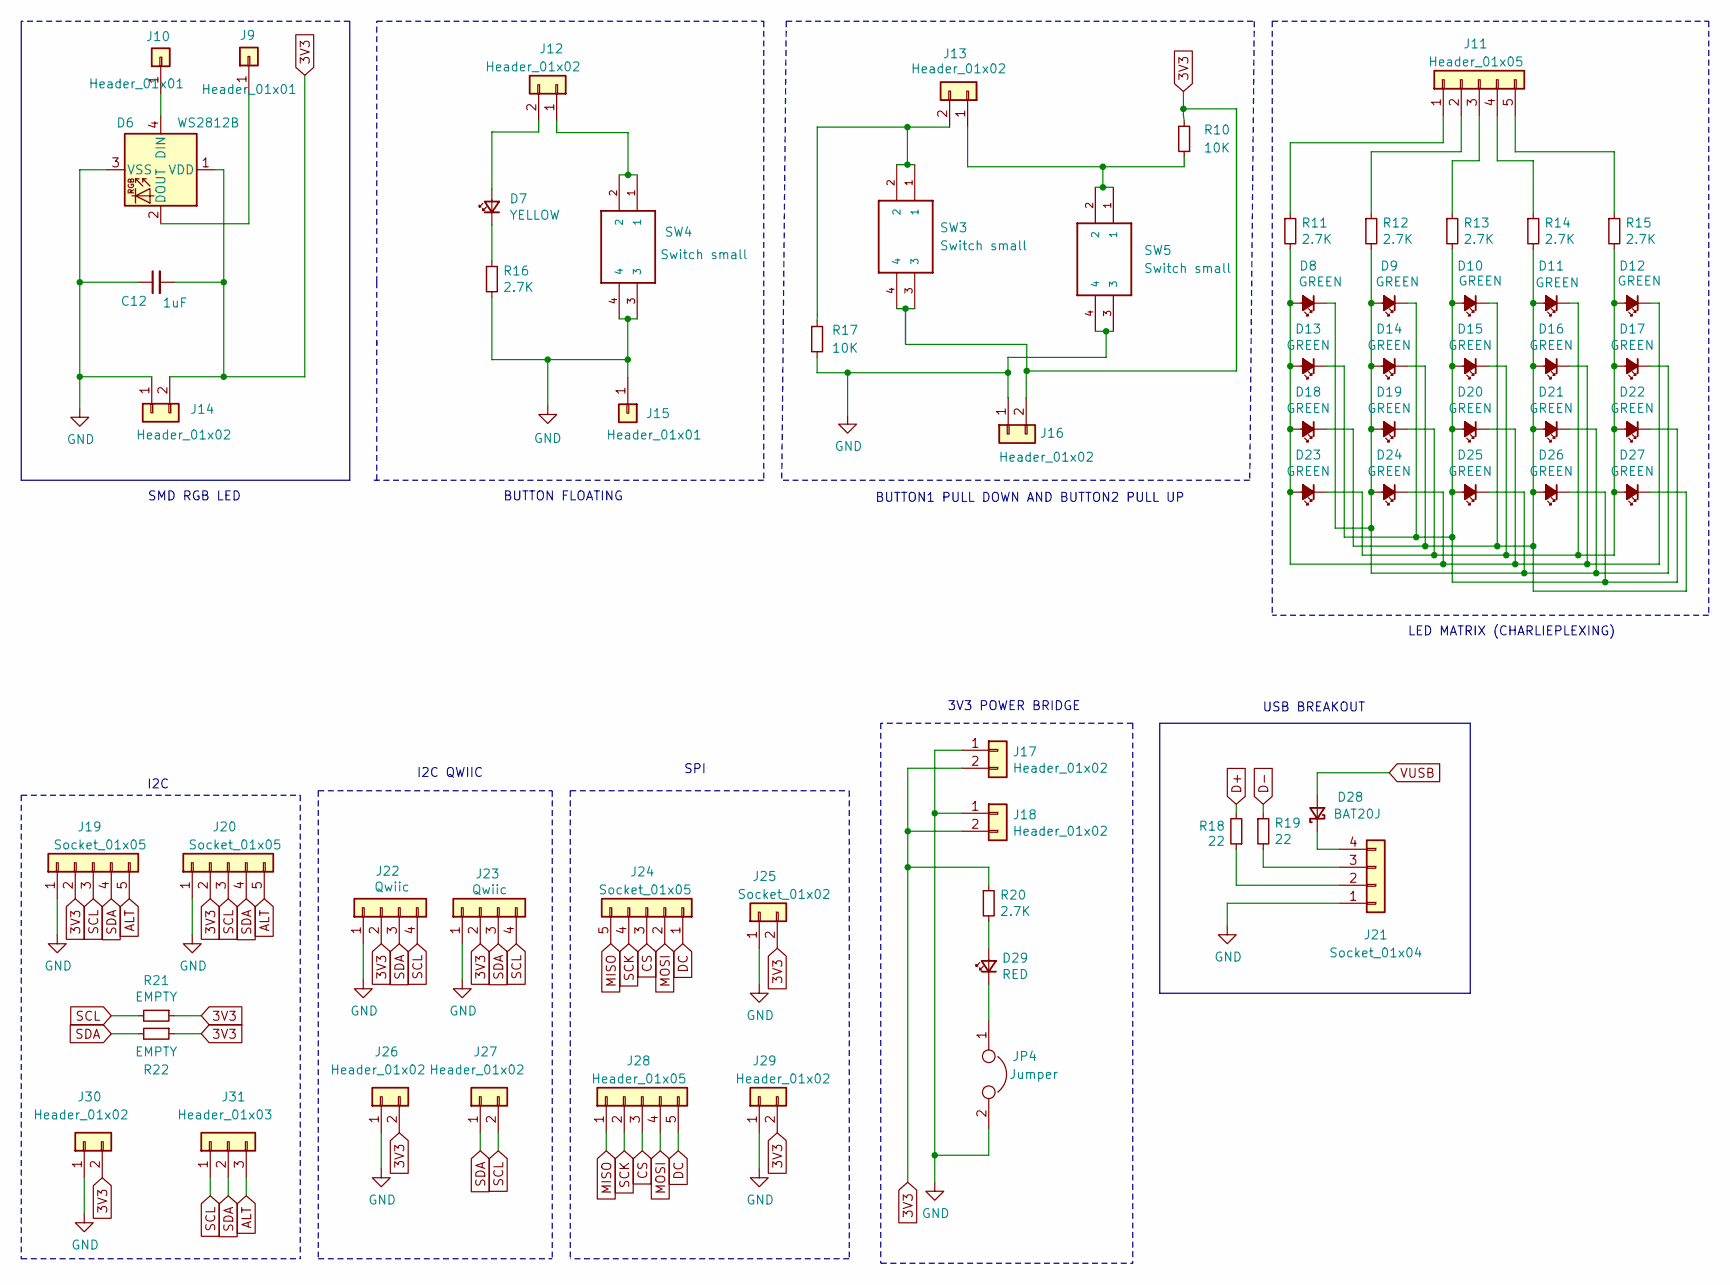
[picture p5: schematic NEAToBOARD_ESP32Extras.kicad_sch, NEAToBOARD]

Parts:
C12: 1uF; C_0805_2012Metric_Pad1.18x1.45mm_HandSolder; MANUFACTURER_PART_NUMBER CL21B105KOFNNNE; LCSC C24123
D6: WS2812B; LED_WS2812B_PLCC4_5.0x5.0mm_P3.2mm; MANUFACTURER_PART_NUMBER WS2812B-B/W; LCSC C2761795
D7: YELLOW; LED_0805_2012Metric_Pad1.15x1.40mm_HandSolder; MANUFACTURER_PART_NUMBER 17-21SYGC/S530-E2/TR8; LCSC C73548
D8, D9, D10, D11, D12, D13, D14, D15, D16, D17, D18, D19, D20, D21, D22, D23, D24, D25, D26, D27: GREEN; LED_0805_2012Metric_Pad1.15x1.40mm_HandSolder; MANUFACTURER_PART_NUMBER XL-2012UGC; LCSC C965815
D28: BAT20J; D_SOD-123; MANUFACTURER_PART_NUMBER B5819W; LCSC C8598
D29: RED; LED_0805_2012Metric_Pad1.15x1.40mm_HandSolder; MANUFACTURER_PART_NUMBER 17-21SURC/S530-A3/TR8; LCSC C72037
J9, J10, J15: Header_01x01; PinHeader_1x01_P2.54mm_Small; LCSC C113597
J11, J28: Header_01x05; PinHeader_1x05_P2.54mm_Vertical; LCSC C113597
J12, J13, J14, J16, J17, J18, J26, J27, J29, J30: Header_01x02; PinHeader_1x02_P2.54mm_Vertical; LCSC C113597
J19, J20, J24: Socket_01x05; PinSocket_1x05_P2.54mm_Vertical; LCSC C50950
J21: Socket_01x04; PinSocket_1x04_P2.54mm_Vertical; LCSC C2718488
J22, J23: Qwiic; CONN_BM04B-SRSS-TB(LF)(SN); MANUFACTURER_PART_NUMBER BM04B-SRSS-TB(LF)(SN); LCSC C160390
J25: Socket_01x02; PinSocket_1x02_P2.54mm_Vertical; LCSC C49661
J31: Header_01x03; PinHeader_1x03_P2.54mm_Vertical; LCSC C113597
JP4: Jumper; SolderJumper-2_P1.3mm_Bridged_Pad1.0x1.5mm_Small
R10, R17: 10K; R_0805_2012Metric_Pad1.20x1.40mm_HandSolder; MANUFACTURER_PART_NUMBER 0805W8F1002T5E; LCSC C17414
R11, R12, R13, R14, R15, R16, R20: 2.7K; R_0805_2012Metric_Pad1.20x1.40mm_HandSolder; MANUFACTURER_PART_NUMBER 0805W8F2701T5E; LCSC C17530
R18, R19: 22; R_0805_2012Metric_Pad1.20x1.40mm_HandSolder; MANUFACTURER_PART_NUMBER 0805W8J0220T5E; LCSC C17561
R21, R22: EMPTY; R_0805_2012Metric_Pad1.20x1.40mm_HandSolder
SW3, SW4, SW5: Switch small; PTS810SJG250SMTRLFS; MANUFACTURER_PART_NUMBER K2-1808SN-A4SW-01; LCSC C92589

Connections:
ALT: J19.5, J20.5, J31.3; also elsewhere on the board
CS: J24.3, J28.3; also elsewhere on the board
D+: R18.2; also elsewhere on the board
D-: R19.1; also elsewhere on the board
DC: J24.1, J28.5; also elsewhere on the board
MISO: J24.5, J28.1; also elsewhere on the board
MOSI: J24.2, J28.4; also elsewhere on the board
unnamed: D6.4 (DIN), J10.1
unnamed: D6.2 (DOUT), J9.1
unnamed: D7.2 (A), J12.2
unnamed: D9.1 (K), D10.2 (A), D13.1 (K), D15.2 (A), D20.2 (A), D22.1 (K), D25.2 (A), D26.1 (K), R13.2
unnamed: D10.1 (K), D11.2 (A), D14.1 (K), D16.2 (A), D18.1 (K), D21.2 (A), D26.2 (A), D27.1 (K), R14.2
unnamed: D8.2 (A), D12.1 (K), D13.2 (A), D16.1 (K), D18.2 (A), D20.1 (K), D23.2 (A), D24.1 (K), R11.2
unnamed: D8.1 (K), D9.2 (A), D14.2 (A), D17.1 (K), D19.2 (A), D21.1 (K), D24.2 (A), D25.1 (K), R12.2
unnamed: D28.1 (K), J21.4
unnamed: D29.2 (A), R20.2
unnamed: D29.1 (K), JP4.1
unnamed: J11.1, R11.1
unnamed: J11.2, R12.1
unnamed: J11.3, R13.1
unnamed: J11.4, R14.1
unnamed: J12.1, SW4.1, SW4.2
unnamed: J13.1, R10.1, SW5.1, SW5.2
unnamed: J13.2, R17.1, SW3.1, SW3.2
unnamed: J21.2, R18.1
unnamed: J21.3, R19.2
SCK: J24.4, J28.2; also elsewhere on the board
VUSB: D28.2 (A); also elsewhere on the board

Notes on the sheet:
I2C QWIIC
LED MATRIX (CHARLIEPLEXING)
USB BREAKOUT
I2C
BUTTON FLOATING
SMD RGB LED
3V3 POWER BRIDGE
SPI
BUTTON1 PULL DOWN AND BUTTON2 PULL UP

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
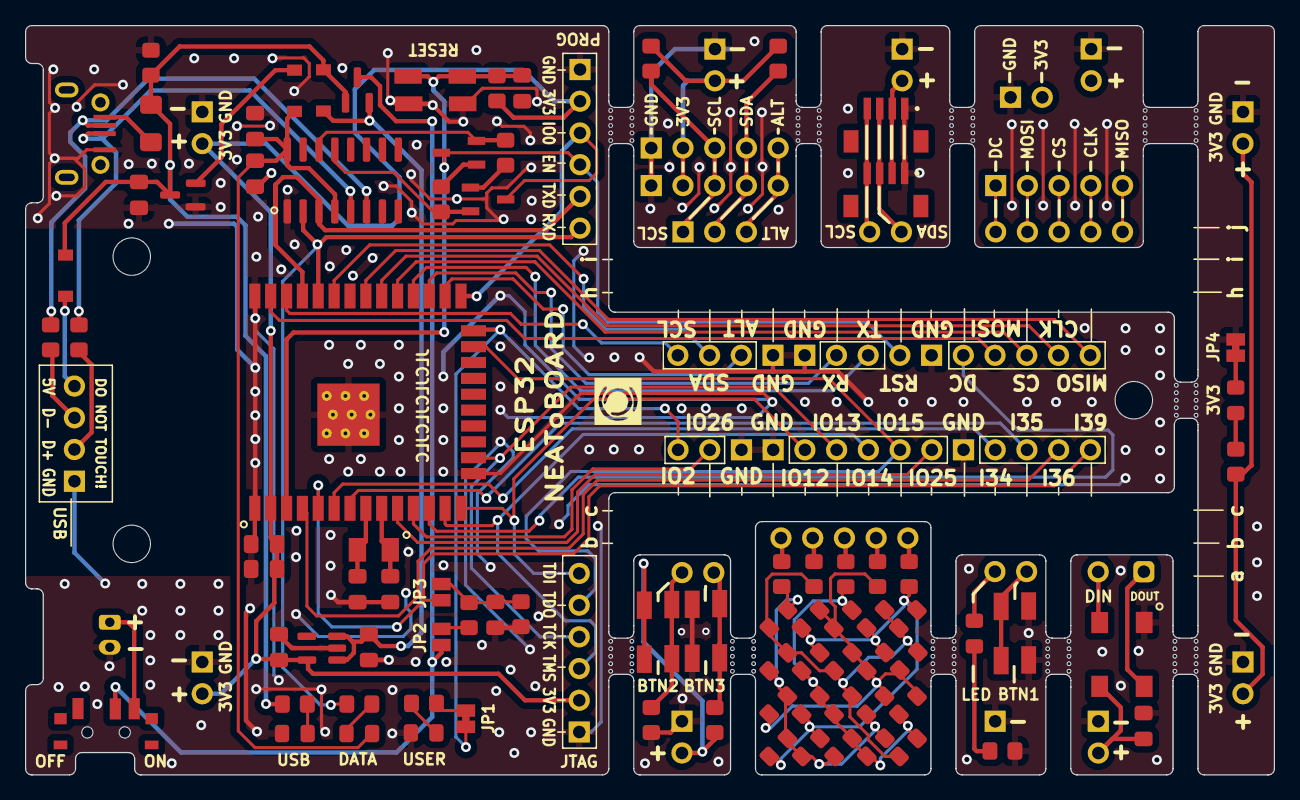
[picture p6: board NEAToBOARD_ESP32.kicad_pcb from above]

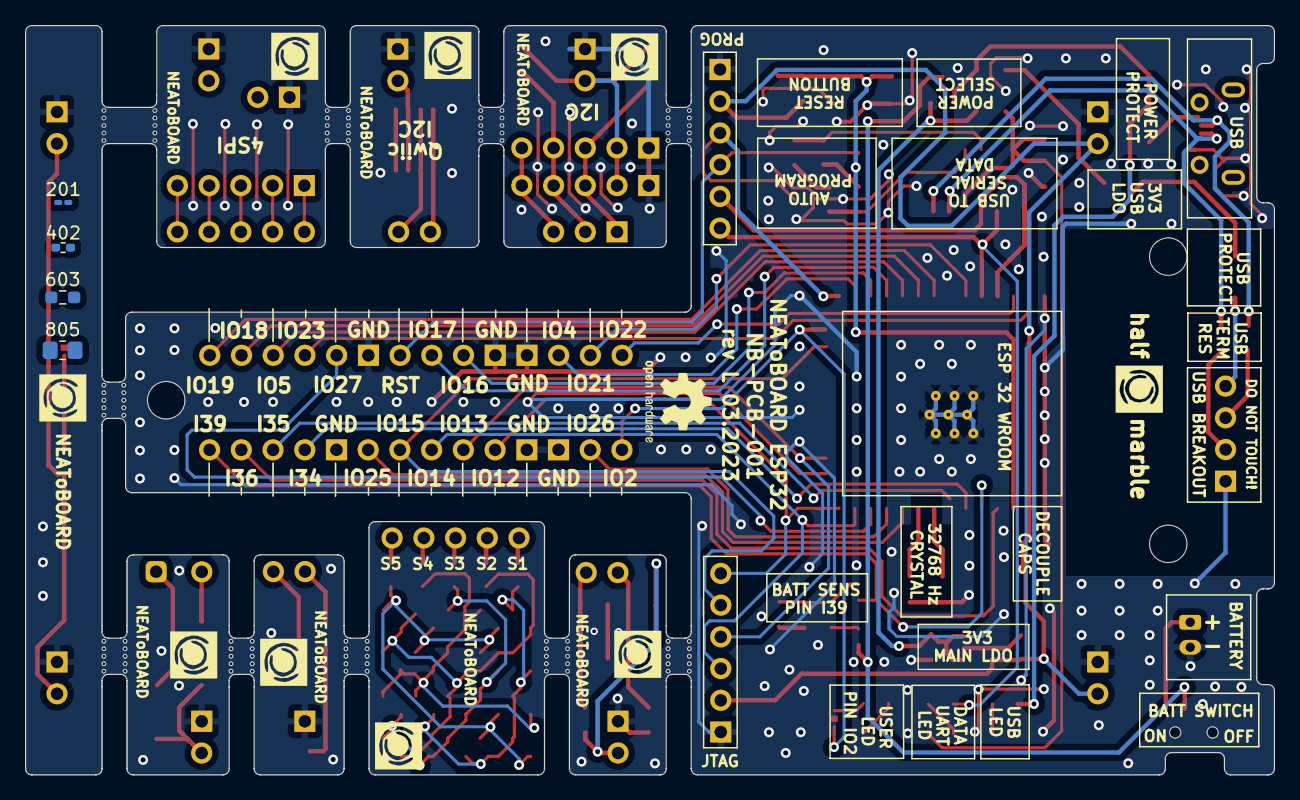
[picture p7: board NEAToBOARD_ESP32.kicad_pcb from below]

Board: 2 copper layers, 100.0 x 60.0 mm, 142 parts (34 on the bottom side), 70 nets.

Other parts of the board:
201: R_0201_0603Metric_Pad0.64x0.40mm_HandSolder
402: R_0402_1005Metric_Pad0.72x0.64mm_HandSolder
603: R_0603_1608Metric_Pad0.98x0.95mm_HandSolder
805: R_0805_2012Metric_Pad1.20x1.40mm_HandSolder
LOGO3#2, LOGO3#3, LOGO3#4, LOGO3#5, LOGO3#6, LOGO3#7, LOGO3#8: Logo_HalfMarble; LOGO
R15#2, R16#2: 2.7K; R_0805_2012Metric_Pad1.20x1.40mm_HandSolder

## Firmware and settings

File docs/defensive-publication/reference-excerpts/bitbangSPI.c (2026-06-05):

// Copyright 2021 Halfmarble LLC
//
// Licensed under the Apache License, Version 2.0 (the "License");
// you may not use this file except in compliance with the License.
// You may obtain a copy of the License at
//
//     http://www.apache.org/licenses/LICENSE-2.0
//
// Unless required by applicable law or agreed to in writing, software
// distributed under the License is distributed on an "AS IS" BASIS,
// WITHOUT WARRANTIES OR CONDITIONS OF ANY KIND, either express or implied.
// See the License for the specific language governing permissions and
// limitations under the License.

#include <math.h>
#include "driver/gpio.h"
#include "driver/periph_ctrl.h"
#include "esp_rom_gpio.h"
#include "hal/gpio_hal.h"
#include "hal/gpio_types.h"

#include "bitbangSPI.h"
#include "utilities.h"

#define WANT_FLAGS (SPI_DEVICE_NO_DUMMY | SPI_DEVICE_3WIRE | SPI_DEVICE_HALFDUPLEX)
#define WANT_CLOCK_HZ (12000000) // want 12MHz, USB full speed (83.3333ns bits)
#define WANT_DUTY_CYCLE (128)    // 50% duty cycle

#define DUMMY_DELAY 0
#define MOSI_DELAY_MODE 0
#define MOSI_DELAY_NUM 4

static inline int setup_clock(int fapb, int hz, int duty_cycle, spi_ll_clock_val_t *out_reg)
{
    int best_n = 0;
    int best_pre = 0;
    uint32_t best_err = 0xFFFFFFFF;
    int best_hz = 0;

    for (int n = 0b000001; n <= 0b111111; n++)
    {
        for (int pre = 0b0000000000001; pre <= 0b1111111111111; pre++)
        {
            int eff_hz = spi_ll_freq_for_pre_n(fapb, pre, n);
            uint32_t errval = abs(eff_hz - hz);
            if (errval <= best_err)
            {
                best_err = errval;

                best_n = n;
                best_pre = pre;
                best_hz = eff_hz;

                //printf("BEST SO FAR CLK %12d:%10d:%10d [%10d:%10d]\n", best_hz, hz, (eff_hz - hz), best_n, best_pre);
            }
        }
    }
    //printf("BEST CLK %12d:%10d [%10d:%10d]\n", best_hz, best_err, best_n, best_pre);

    typeof(SPI1.clock) reg;
    reg.clkcnt_n = best_n - 1;
    reg.clkdiv_pre = best_pre - 1;
    reg.clkcnt_h = floor(best_n / 2 - 1);
    reg.clk_equ_sysclk = 0;

    *(uint32_t *)out_reg = reg.val;

    return best_hz;
}

esp_err_t bitbang_init(bitbang_t *bitbang, bitbang_buffers_t buffers, spi_host_device_t host_device, int8_t mosi, bool delay)
{
    memset(bitbang, 0, sizeof(bitbang_t));

    bitbang->hal = heap_caps_malloc(sizeof(spi_hal_context_t), MALLOC_CAP_INTERNAL | MALLOC_CAP_8BIT);
    if (bitbang->hal == NULL)
    {
        return ESP_ERR_NO_MEM;
    }
    memset(bitbang->hal, 0, sizeof(spi_hal_context_t));

    bitbang->hal_dev = heap_caps_malloc(sizeof(spi_hal_dev_config_t), MALLOC_CAP_INTERNAL | MALLOC_CAP_8BIT);
    if (bitbang->hal_dev == NULL)
    {
        return ESP_ERR_NO_MEM;
    }
    memset(bitbang->hal_dev, 0, sizeof(spi_hal_dev_config_t));

    bitbang->buffers.write.buffer = buffers.write.buffer;
    bitbang->buffers.write.length = 0;

    bitbang->buffers.read.buffer = buffers.read.buffer;
    bitbang->buffers.read.length = 0;

    bitbang->hal->hw = SPI_LL_GET_HW(host_device);
    bitbang->hal->dma_enabled = 0;

    static spi_ll_clock_val_t clock_reg = 0;
    if (clock_reg == 0)
    {
        setup_clock(SPI_LL_PERIPH_CLK_FREQ, WANT_CLOCK_HZ, WANT_DUTY_CYCLE, &clock_reg);
    }

    periph_module_enable(spi_periph_signal[host_device].module);

    // invert the D+ line to keep it HIGH when idle
    // the D+ is the 2nd line, i.e. the one that starts
    // transmitting later aka not the one that needs the delayed start
    bool invert = !delay;
    esp_rom_gpio_connect_out_signal(mosi, spi_periph_signal[host_device].spid_out, invert, false);
    esp_rom_gpio_connect_in_signal(mosi, spi_periph_signal[host_device].spid_in, invert);
    gpio_hal_iomux_func_sel(GPIO_PIN_MUX_REG[mosi], PIN_FUNC_GPIO);

    // make it easy for a device to overpower the host D-/D+ lines
    gpio_set_drive_capability(mosi, GPIO_DRIVE_CAP_0); // weakest
    esp_rom_gpio_pad_set_drv(mosi, 0); // 5mA

    spi_dev_t *hw = bitbang->hal->hw;
    spi_ll_master_init(hw);
    spi_ll_master_set_mode(hw, 0);
    spi_ll_master_set_io_mode(hw, SPI_LL_IO_MODE_NORMAL);
    spi_ll_master_set_clock_by_reg(hw, &clock_reg);
    spi_ll_disable_int(hw);
    spi_ll_clear_int_stat(hw);
    spi_ll_set_rx_lsbfirst(hw, 0);
    spi_ll_set_tx_lsbfirst(hw, 0);
    spi_ll_set_sio_mode(hw, (WANT_FLAGS & SPI_DEVICE_3WIRE ? 1 : 0));
    spi_ll_set_half_duplex(hw, (WANT_FLAGS & SPI_DEVICE_HALFDUPLEX ? 1 : 0));
    spi_ll_set_addr_bitlen(hw, 0);
    spi_ll_set_command_bitlen(hw, 0);
    spi_ll_set_address(hw, 0, 0, 0);
    spi_ll_set_command(hw, 0, 0, 0);
    spi_ll_enable_mosi(hw, 1); // enable MOSI phase only

    if (delay)
    {
        // delay this SPI MOSI line to sync up with the other one
        spi_ll_set_dummy(bitbang->hal->hw, DUMMY_DELAY);                          // in full clocks (1/2 period)
        spi_ll_set_mosi_delay(bitbang->hal->hw, MOSI_DELAY_MODE, MOSI_DELAY_NUM); // in 1/8th of the period
    }

    return ESP_OK;
}

inline static void bitbang_write_setup(spi_dev_t *hw, uint8_t *buffer, size_t length)
{
    spi_ll_set_mosi_bitlen(hw, length);
    spi_ll_write_buffer(hw, buffer, length);
}

// only 19th bit set
IRAM_ATTR static const uint32_t ONE = 0b00000000000001000000000000000000;

// synchronized write of 2 SPIs units
IRAM_ATTR void bitbang_write_impl(bitbang_t *bb1, bitbang_t *bb2, bool block)
{
    register spi_dev_t *spi1 = bb1->hal->hw;
    register spi_dev_t *spi2 = bb2->hal->hw;

    __asm__ __volatile__("excw;");                            // wait until all prior instructions are either exception free or any exceptions have been taken
    __asm__ __volatile__("isync;dsync;esync;");               // wait till all kind of syncs are done
    __asm__ __volatile__("nop;nop;nop;nop;nop;nop;nop;nop;"); // quiet down the CPU

    // start both SPIs at hopefully the same time
    // spi1 will be delayed const time wrt spi2, since it starts 1st
    spi1->cmd.val = ONE; //spi1->cmd.usr = 1;
    spi2->cmd.val = ONE; //spi2->cmd.usr = 1;

    if (block)
    {
        while (spi1->cmd.usr || spi2->cmd.usr)
        {
            // busy spin loop waiting for the data transmission to end
            NOP();
        }
    }
}

IRAM_ATTR uint64_t bitbang_write(bitbang_t *bb1, bitbang_t *bb2, bool block)
{
    bitbang_write_setup(bb1->hal->hw, bb1->buffers.write.buffer, bb1->buffers.write.length);
    bitbang_write_setup(bb2->hal->hw, bb2->buffers.write.buffer, bb2->buffers.write.length);
    
    uint64_t stamp = esp_timer_get_time();
    bitbang_write_impl(bb1, bb2, block);
    
    return stamp;
}

IRAM_ATTR void bitbang_read(bitbang_t *bb1, bitbang_t *bb2, bool block)
{
    // TODO
}

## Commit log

2023-12-31 add KiCad project
    [NEAToBOARD_ESP32.kicad_pcb, NEAToBOARD_ESP32.kicad_sch, NEAToBOARD_ESP32Extras.kicad_sch]
2024-01-01 add schematic
2024-01-01 move KiCad files into its own folder, add 3d model
    [NEAToBOARD_ESP32.kicad_pcb, NEAToBOARD_ESP32.kicad_sch, NEAToBOARD_ESP32Extras.kicad_sch]
2024-01-02 add missing LEDs
2026-06-04 Relicense to CERN-OHL-P, add BOM/fab configs, fix libraries, scrub leaks
    - Relicense hardware design to CERN-OHL-P-2.0 (was MIT)
    - Add vendor-neutral BOM.csv (convenience export of the schematic)
    - Add board2pdf + InteractiveHtmlBom plugin configs (local path scrubbed),
    the rendered interactive BOM (bom/), and pinout source (pinout/)
    - Fix ALS-PT19 footprint 3D-model path to HalfMarble.3dshapes
    - Add sym-lib-table registering the custom project symbols
    - Remove generated netlist XML that leaked a local/private filesystem path
    - Ignore LibreOffice lock files; expand README (firmware, schematic links,
    acknowledgements, layout)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
    [BOM.csv]
2026-06-05 Add defensive publication: dual-SPI synchronized differential-output technique
    Publishes, as dated prior art (DOI 10.5281/zenodo.20558155), a method for
    generating a synchronized two-line/differential signal — e.g. a bit-banged USB
    full-speed D-/D+ pair — by driving two independent SPI controllers in lock-step:
    a CPU-fenced back-to-back start makes the inter-unit skew deterministic, and a
    fixed configured MOSI delay cancels it open-loop.
    Includes the disclosure paper (markdown + rendered PDF), a prior-art comparison,
    and load-bearing source excerpts (bitbangSPI.c, ubbPackets.c, crc.c + headers,
    Apache-2.0). A Makefile + style.css reproduce the PDF (pandoc + headless Chrome,
    `make pdf`).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
    [bitbangSPI.c]
